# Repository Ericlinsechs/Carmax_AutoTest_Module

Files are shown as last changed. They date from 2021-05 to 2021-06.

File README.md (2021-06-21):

# 自動化治具盒 Carmax Auto-test Module

- Github URL : https://github.com/Ericlinsechs/Carmax_AutoTest_Module
- This module is featured by conbining several test functions into one single box, the functions of it contains :
1. 深度測試功能
2. 布條紋測試功能
3. AOA斷線測試功能
4. 電流檢測功能
5. 連續紀錄10秒電流值功能

# How to use it

If you want to carry out tests immediately instead of editing the code or change the hardware, this chapter is fitting on you.

## Prerequisites

Before start using it, there are some stuffs you need to prepare.

- The components of the module include :
1. Auto-test module
2. 12V power cable (alligator clip)
3. Current monitor adapter
<p align="left">
  hover text
</p>

- Some extra components are required :
1. USB outlet power adapter
2. USB to micro-USB cable
3. 12v power supplyer
<p align="left">
  hover text
</p>

## Usage

### Hardware Setting Up
1. Connecting 5v power cable to the module.
<p align="left">
  hover text
</p>

2. Connecting 12v power cable to power supplyer.
<p align="left">
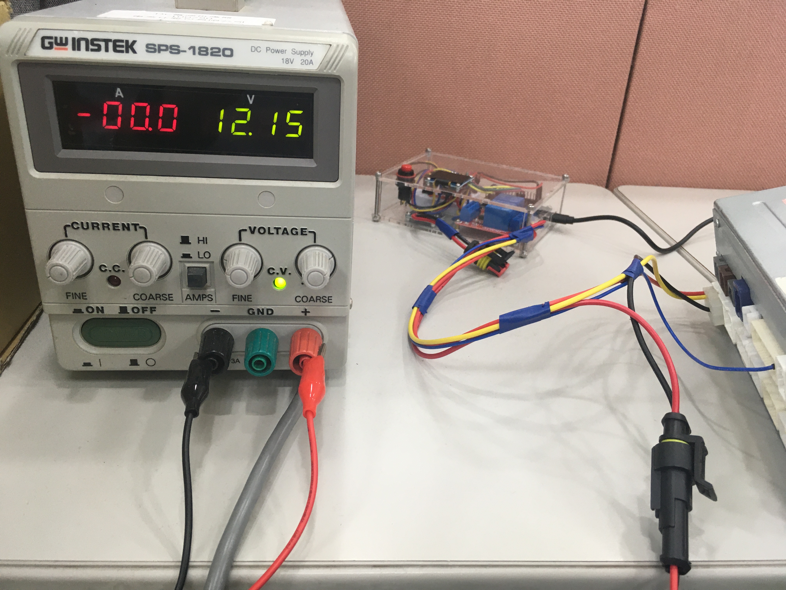
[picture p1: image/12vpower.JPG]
  
</p>

3. Connecting the connector below to DA machine.
<p align="left">
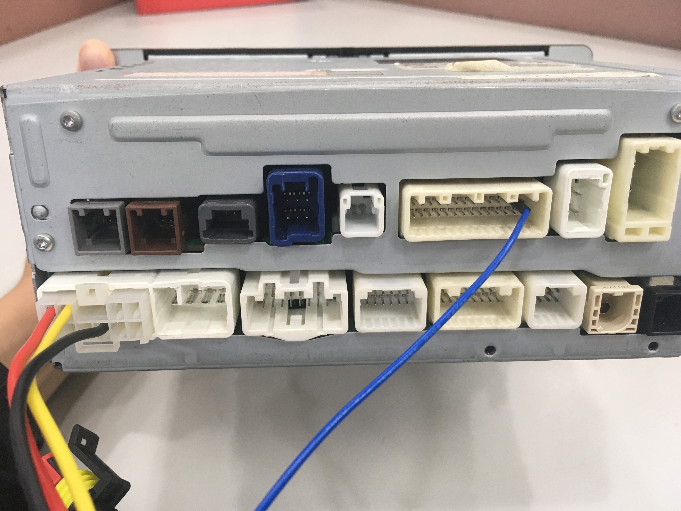
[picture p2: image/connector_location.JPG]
  
</p>

4. Connecting the Rev pin below to DA machine(connect to Pin No.2 from top right side of the connector).
<p align="left">
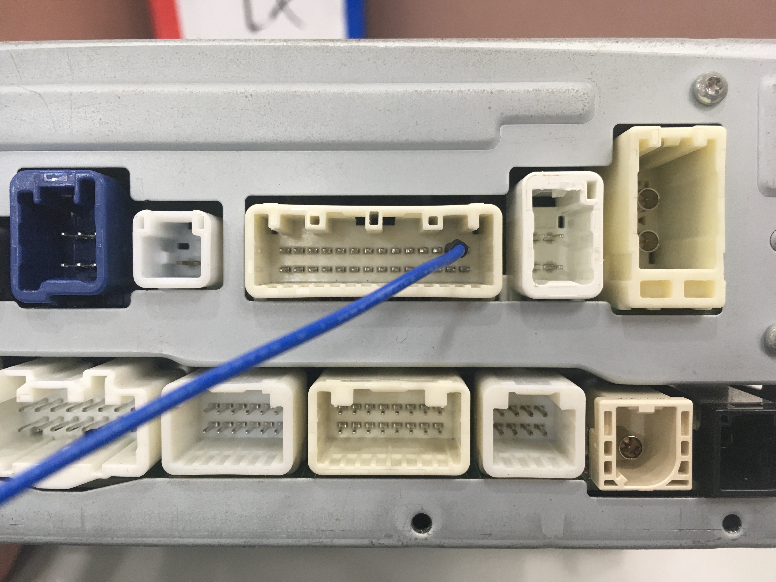
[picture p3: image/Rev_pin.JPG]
  
</p>

5. Connecting to electronic object(ex: E-mirror) serially(Only function No.4 and No.5 needed).

### Getting Started
1. Once 5v power cable is connected, you would see the **welcome message** on the displayer on the box.
<p align="left">
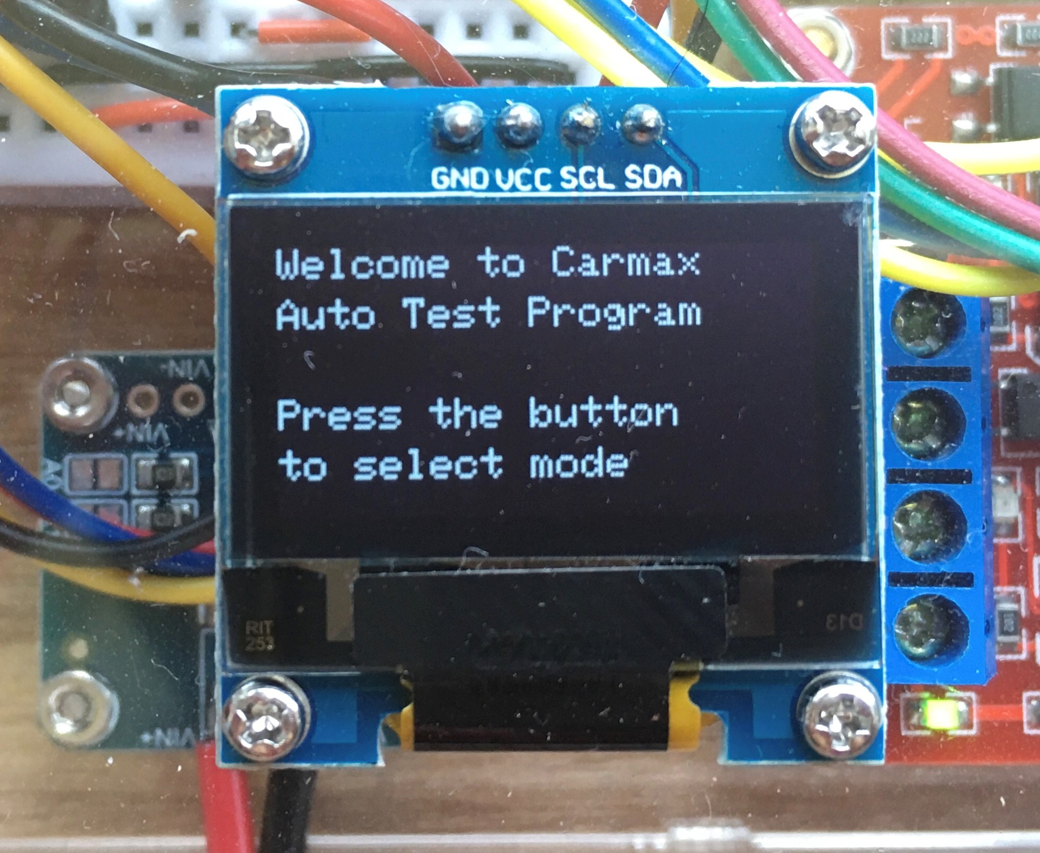
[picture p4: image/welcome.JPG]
  
</p>

2. After press the button on the left side of the displayer, it would enter mode selecting process, choose which test function you want to run it.
<p align="left">
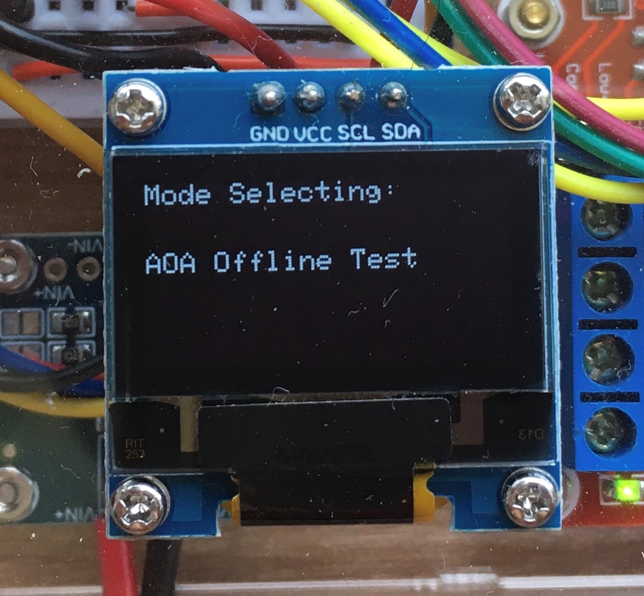
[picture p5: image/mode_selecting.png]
  
</p>

3. When you finish your selecting, mode selecting process will be ended after 5 seconds (the countdown is on the bottom right side of the displayer).
4. Before the test is running, you would see the **ready to test** message.
<p align="left">
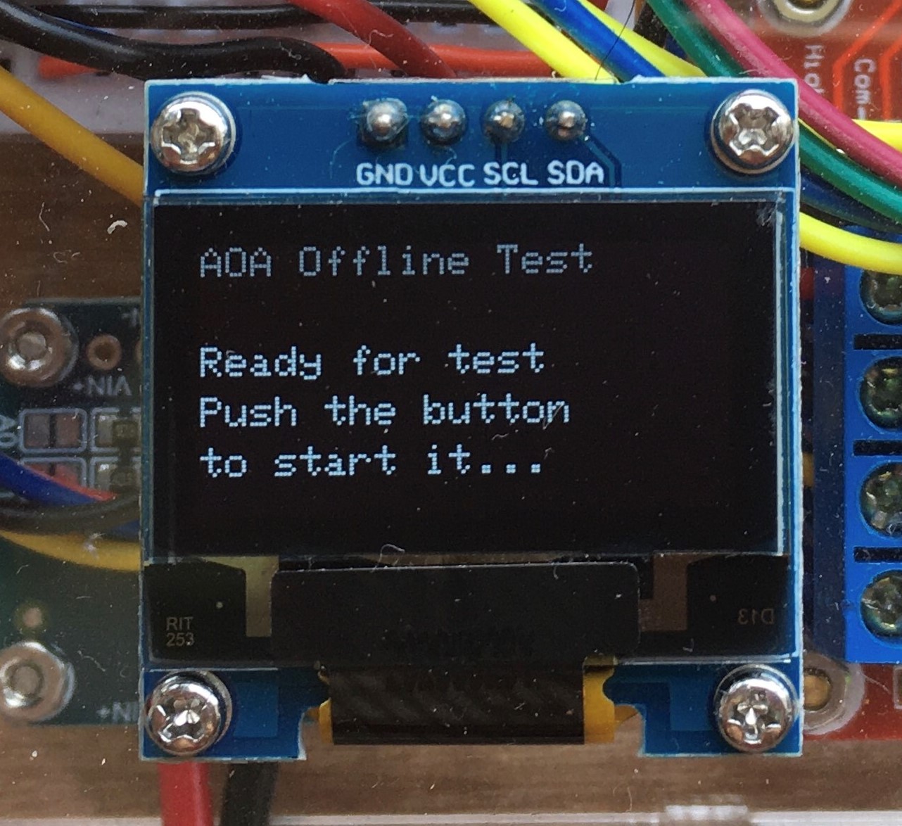
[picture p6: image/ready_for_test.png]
  
</p>

5. Press the button again to start the test.

### Function No.5 (連續紀錄10秒電流值功能)
#### Software
- [python 3.7.4](https://www.python.org/downloads/windows/) 
- [Atom python editor](https://atom.io/) (addition)
- [Anaconda3](https://www.anaconda.com/products/individual#Downloads)
- [pip](https://pip.pypa.io/en/stable/installing/)
- Python Pandas Package
  - `pip install pandas`
- Python Numpy Package
  - `pip install numpy`
- Python Requests Package 
  - `pip install requests`
- Python Beautifulsoup4 Package 
  - `pip install beautifulsoup4` 

#### Wifi Connection
- Due to upload current measurements onto website, wifi connecting is essential. 
1. Connecting Wifi is required when running the function No.5, default wifi setting is Samsung Galaxy Noto 20, if you want to change wifi, please check [current_monitor.h](https://github.com/Ericlinsechs/Carmax_AutoTest_Module/blob/main/code/Auto_Test_Box_code/libraries/Current_Monitor/Current_Monitor.h).
<p align="left">
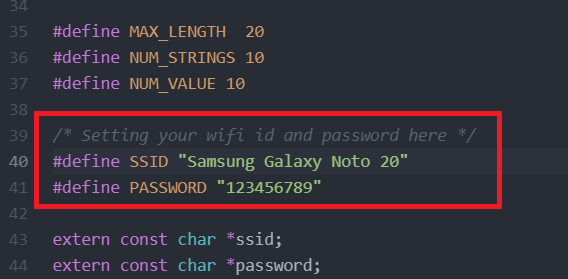
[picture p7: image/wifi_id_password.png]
  
</p>

2. Connect the same Wifi as the auto-test box did on your computer, then search the IP on the website.
<p align="left">
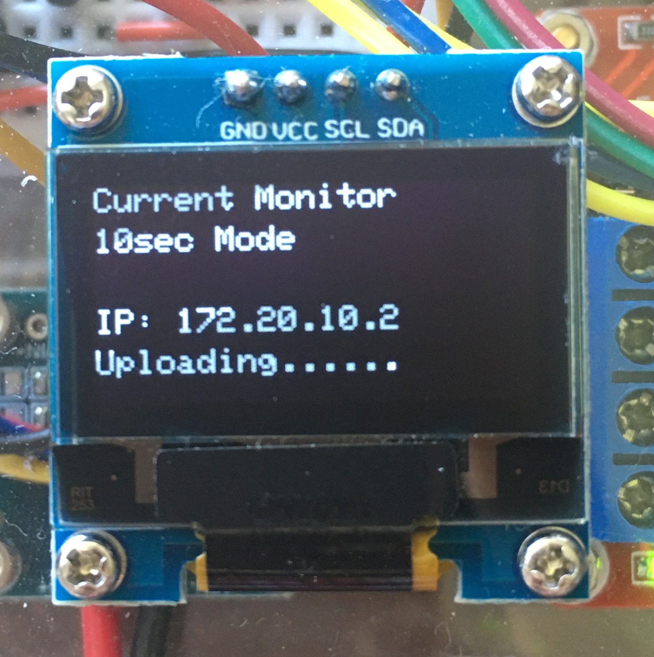
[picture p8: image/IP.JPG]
  
</p>

3. You should see the current measurement on the webpage.
<p align="left">
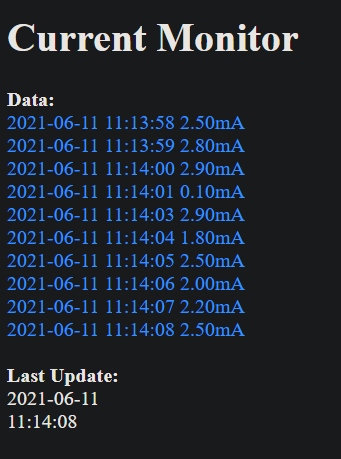
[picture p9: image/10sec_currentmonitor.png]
  
</p>

#### Webcrawler
- This part describes how we crawl the data from website and then save as a .csv file.
1. After installed Anaconda3, add these route to [PATH](https://helpdeskgeek.com/windows-10/add-windows-path-environment-variable/) :
  - `C:\Users\username\Anaconda3`
  - `C:\Users\username\Anaconda3\Scripts`
  - `C:\Users\username\Anaconda3\Library\bin`
2. Find [webcrawler_code.py](https://github.com/Ericlinsechs/Carmax_AutoTest_Module/blob/main/code/webcrawler_code/webcrawler_code.py) on your computer and open it.
3. Create a CSV file on your computer.
<p align="left">
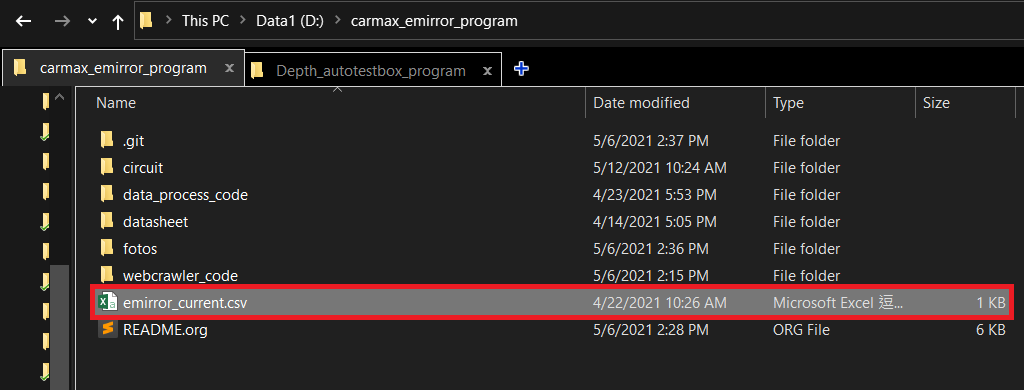
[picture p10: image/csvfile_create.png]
  
</p>

4. Change IP and route of the CSV file you just created.
<p align="left">
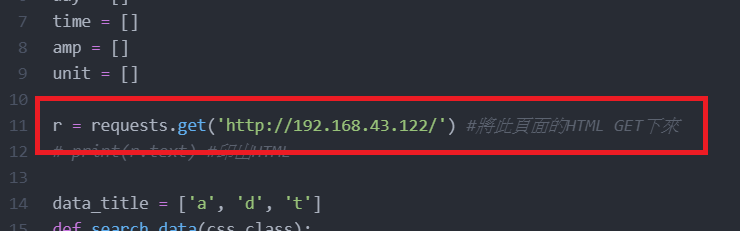
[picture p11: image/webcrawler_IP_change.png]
  
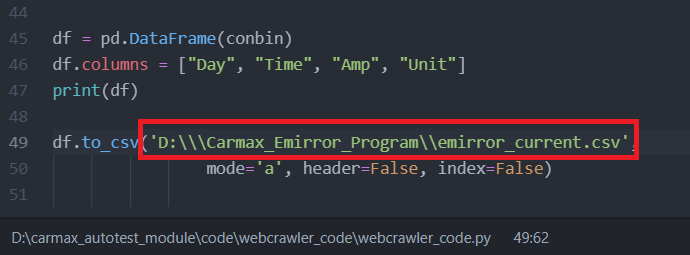
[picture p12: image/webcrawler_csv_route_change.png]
  
</p>

5. Run `pyhton [route]/webcrawler_code.py` on cmd and check the data in CSV file.

- [Tutorial Reference](https://ithelp.ithome.com.tw/articles/10202121)

#### Windows Task Manager
- Using Windows task manager to run webcrawler code automatically.
- [Batch file](https://github.com/Ericlinsechs/Carmax_AutoTest_Module/blob/main/code/webcrawler_code/emirror_crawler.bat)
- [Tutorial Reference](https://titangene.github.io/article/set-up-windows-task-scheduler-to-periodically-execute-python-crawler.html)
#### Conda environment (if needed)
- [Tutorial Reference](https://titangene.github.io/article/create-a-virtual-environment-and-manage-dependencies-with-conda.html)
### **CAUTION**
- It's designed to be **non-stop** on each test function.
- If you desire a halt during the test, press the button between the time a test round is done and next one haven't start yet.
- Before function No.4 or No.5 is running, please make sure the voltage and current won't over the spec bellow :
  - **MAX voltage: 32v current: 1A (default)**
# Pin Definition
<p align="left">
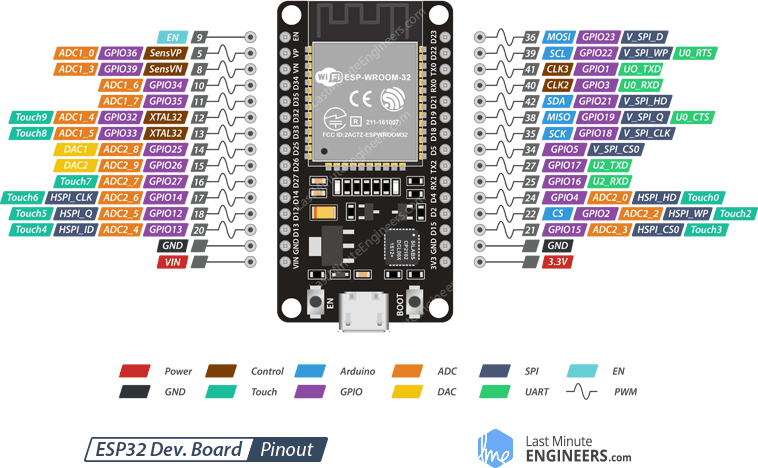
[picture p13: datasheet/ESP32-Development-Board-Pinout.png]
  
</p>

<p align="left">
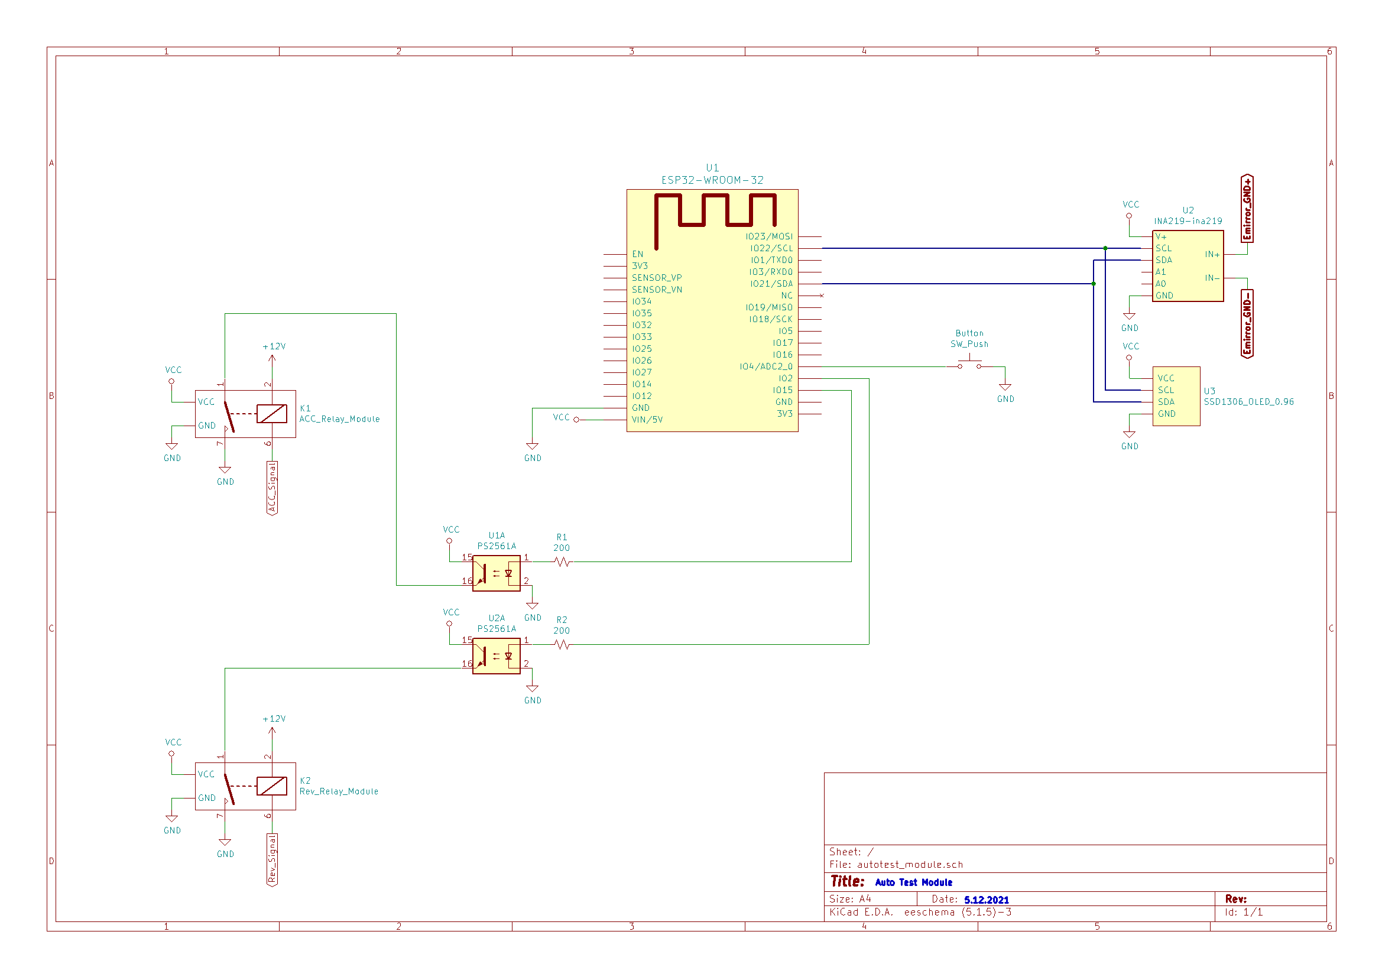
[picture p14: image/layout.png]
  
</p>

# Code Uploading Set Up (addition)
Only for code uploaded requirement would need to check this chapter.

## Prerequisites
### Software
- [ArduinoIDE](https://www.arduino.cc/en/software)
- [Atom python editor](https://atom.io/)
- [python 3.7.4](https://www.python.org/downloads/windows/) 

## Getting Started
### Installation
- Copy this `git clone https://github.com/Ericlinsechs/Carmax_AutoTest_Module.git /.` to your terminal(cmd or so on) and exeuted.
- Copy these [libraries](https://github.com/Ericlinsechs/Carmax_AutoTest_Module/tree/main/code/Auto_Test_Box_code/libraries) into this path(default)`C:\Users\[Username]\Documents\Arduino\libraries`
- Copy [auto_Test_Box_Program](https://github.com/Ericlinsechs/Carmax_AutoTest_Module/tree/main/code/Auto_Test_Box_code/Auto_Test_Box_Program) dir into this path(default)`C:\Users\[Username]\Documents\Arduino`
##### ESP32 Setting
- Stable release link: `https://raw.githubusercontent.com/espressif/arduino-esp32/gh-pages/package_esp32_index.json`
- Enter the release links above into Additional Board Manager URLs field.
- Run the command below to install esp32 package :
  - `git clone "https://github.com/espressif/arduino-esp32.git" C:/Users/[YOUR_USER_NAME]/Documents/Arduino/hardware/espressif/esp32`
  - `git submodule update --init --recursive`
- Open `[ARDUINO_SKETCHBOOK_DIR]/hardware/espressif/esp32/tools and double-click get.exe`
- Now you should upload the code without error.
- [Tutorial Reference](https://github.com/espressif/arduino-esp32)
#### Arduino library
- Install Adafruit Library
  - `Adafruit ina219 library`
  - `Adafruit GFX library` 
  - `Adafruit ssd1306 library`
- Install The Network Time Protocol (NTP) Library
  - [NTP library link](https://github.com/taranais/NTPClient)
 ### Code uploading
 - [Tutorial Reference](https://www.arduino.cc/en/Tutorial/getting-started-with-ide-v2/ide-v2-uploading-a-sketch)
 - Press BOOT button everytime when you upload code, then press RESET to exeucte it.
 - It may cause a bit time to upload, please be patient.
 # Additional Reference
 - [ESP32 Arduino: Getting started with WiFi](https://techtutorialsx.com/2017/06/29/esp32-arduino-getting-started-with-wifi/)
 - [I2C Scanner](https://create.arduino.cc/projecthub/abdularbi17/how-to-scan-i2c-address-in-arduino-eaadda)
 - [Adafruit_INA219](https://learn.adafruit.com/adafruit-ina219-current-sensor-breakout)
 - [Adafruit_SSD1306](https://github.com/adafruit/Adafruit_SSD1306)

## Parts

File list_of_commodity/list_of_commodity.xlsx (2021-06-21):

Cost summary |  | 統編: 22660624 抬頭:車美仕股份有限公司
Line Num. | Order Status | Name of commodity | Desription | Each One Needed | Total Needed | Unit Cost | Quantity | Deliver Cost | Total Cost | Tax | URL
1 | V | 壓克力板加工 |  | 1 | 3 | $945.00 | 1 |  | $945.00 | V | 阿宏 (https://shopee.tw/product/9171064/2037578994)
2 | V | M2*4+3 六角銅柱 | M2 六角長度: 4 牙長: 5 牙距: 0.4 | 12 | 36 | $2.00 | 44 | $50.00 | $138.00 | V | (M2)(M3)(M4)單通六角銅柱 (https://shopee.tw/(M2)(M3)(M4)%E5%96%AE%E9%80%9A%E5%85%AD%E8%A7%92%E9%8A%85%E6%9F%B1-%E5%A4%9A%E7%A8%AE%E5%85%AD%E8%A7%92%E6%9F%B1%E9%95%B7%E5%BA%A6%E5%8F%AF%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)
3 | V | M2 螺絲 | M2*6 頭d : 3.2 thick : 1.6 | 16 | 48 | $2.00 | 60 | $50.00 | $170.00 | V | 樂泰膠水 磁鐵 螺絲 螺帽 木工 塑膠螺絲(全館含稅附發票) (https://shopee.tw/%E3%80%90%E8%AB%8B%E8%A9%A2%E5%83%B9%E5%BE%8C%E8%B3%BC%E8%B2%B7%E3%80%91%E4%B8%8D%E9%8F%BD%E9%8B%BC%E7%99%BD%E9%90%B5-m1-m1.2-m1.4-m1.6-m2-%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)
3 | V | M2 螺帽 | 六角對邊: 4 厚度: 1.6 unit : 10 | 32 | 96 | $10.00 | 6 |  | $60.00 | V | 樂泰膠水 磁鐵 螺絲 螺帽 木工 塑膠螺絲(全館含稅附發票) (https://shopee.tw/%E3%80%90%E8%AB%8B%E8%A9%A2%E5%83%B9%E5%BE%8C%E8%B3%BC%E8%B2%B7%E3%80%91%E4%B8%8D%E9%8F%BD%E9%8B%BC%E7%99%BD%E9%90%B5-m1-m1.2-m1.4-m1.6-m2-%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)
4 | V | M3 螺帽 | 六角對邊: 5.5 厚度: 2.4 unit : 10 | 4 | 12 | $10.00 | 2 |  | $20.00 | V | m3不鏽鋼螺帽 (https://shopee.tw/m2m2.-5-m2.6-m3-m3.5-m4-m5-m6-m8m10-m12%E4%B8%8D%E9%8F%BD%E9%8B%BC%E8%9E%BA%E5%B8%BD-%E7%99%BD%E9%90%B5%E5%85%AD%E8%A7%92%E8%9E%BA%E5%B8%BD-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)
5 | V | M3 螺絲 | M3*35 白鐵有頭內六角 unit : 10支 | 4 | 12 | $25.00 | 2 |  | $50.00 | V | 白鐵螺絲 M3 (https://shopee.tw/%E7%89%99%E5%BE%91m3*%E9%95%B74~60mm%E5%90%84%E5%B0%BA%E5%AF%B8%E4%B8%8D%E9%8F%BD%E9%8B%BC%E6%9D%AF%E9%A0%AD%E5%85%A7%E5%85%AD%E8%A7%92-%E7%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)
6 | V | AMP型 HID 接頭 | 1.5mm 端子 3P | 1 | 3 | $25.00 | 5 | $50.00 | $175.00 | V | louishoma (https://shopee.tw/product/3001351/7240589310)
6 | V | AMP型 HID 接頭 | 1.5mm 端子 2P | 1 | 3 | $20.00 | 5 |  | $100.00 | V | louishoma (https://shopee.tw/product/3001351/7240589310)
7 | V | AMP型 1.5mm端子 | 公 | 5 | 15 | $3.00 | 10 |  | $30.00 | V | louishoma (https://shopee.tw/AMP-%E5%BF%AB%E9%80%9F%E6%8E%A5%E9%A0%AD-%E5%85%AC%E7%AB%AF%E5%AD%90(%E5%90%AB%E9%BB%83%E8%89%B2%E6%A9%A1%E8%86%A0%E5%A1%9E%E5%AD%90)-3%E5%8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)
8 | V | AMP型 1.5mm端子 | 母 | 5 | 15 | $3.00 | 20 |  | $60.00 | V | louishoma (https://shopee.tw/AMP-%E5%BF%AB%E9%80%9F%E6%8E%A5%E9%A0%AD-%E5%85%AC%E7%AB%AF%E5%AD%90(%E5%90%AB%E9%BB%83%E8%89%B2%E6%A9%A1%E8%86%A0%E5%A1%9E%E5%AD%90)-3%E5%8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)
9 | V | 圓型開關 | 10mm 小開關 圓型開關 | 1 | 3 | $15.00 | 4 | $50.00 | $110.00 | V | 祥昌電子 (https://shopee.tw/%E3%80%90%E7%A5%A5%E6%98%8C%E9%9B%BB%E5%AD%90%E3%80%9110mm-%E5%B0%8F%E9%96%8B%E9%97%9C-%E5%9C%93%E5%9E%8B%E9%96%8B%E9%97%9C-%E5%9C%93%E5%BD%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)
10 | V | 20 AWG線材 | 紅 unit : 1M | 1 | 3 | $6.00 | 5 |  | $30.00 | V | 祥昌電子 (https://shopee.tw/%E3%80%90%E7%A5%A5%E6%98%8C%E9%9B%BB%E5%AD%90%E3%80%91UL1007%E5%A4%9A%E8%8A%AF%E7%B7%9A-16AWG-18AWG-20AWG-24AWG-28AWG-%E6%B1%BD%E6%A9%9F%E8%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)
11 | V | 20 AWG線材 | 黑 unit : 1M | 1 | 3 | $7.00 | 5 |  | $35.00 | V | 祥昌電子 (https://shopee.tw/%E3%80%90%E7%A5%A5%E6%98%8C%E9%9B%BB%E5%AD%90%E3%80%91UL1007%E5%A4%9A%E8%8A%AF%E7%B7%9A-16AWG-18AWG-20AWG-24AWG-28AWG-%E6%B1%BD%E6%A9%9F%E8%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)
12 | V | 熱縮套管 | 4mm(黑) unit : 1m | 1 | 3 | $12.00 | 5 |  | $60.00 | V | 祥昌電子 (https://shopee.tw/%E3%80%90%E7%A5%A5%E6%98%8C%E9%9B%BB%E5%AD%90%E3%80%91UL1007%E5%A4%9A%E8%8A%AF%E7%B7%9A-16AWG-18AWG-20AWG-24AWG-28AWG-%E6%B1%BD%E6%A9%9F%E8%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)
13 | V | ESP-WROOM-32 | ESP32 開發板 WIFI+藍牙 | 1 | 3 | $195.00 | 3 | $50.00 | $635.00 | V | 樂意創客 (https://shopee.tw/%E3%80%90%E6%A8%82%E6%84%8F%E5%89%B5%E5%AE%A2%E5%AE%98%E6%96%B9%E5%BA%97%E3%80%91%E3%80%8A%E9%99%84%E7%99%BC%E7%A5%A8%E3%80%8BESP32-%E9%96%8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)
14 | V | SSD1306 oled 0.96吋 | OLED顯示器 | 1 | 3 | $120.00 | 3 |  | $360.00 | V
15 | V | INA219 | 電源監控感測器模組感測器 | 1 | 3 | $58.00 | 3 | $50.00 | $224.00 | V | allen (https://shopee.tw/%E2%96%BA938%E2%97%84INA219-I2C-%E4%BB%8B%E9%9D%A2%E9%9B%B6%E6%BC%82%E7%A7%BB-%E9%9B%99%E5%90%91%E9%9B%BB%E6%B5%81-%E9%9B%BB%E6%BA%90%E7%9B%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)
16 | V | 迷你麵包板 | 迷你麵包板 | 1 | 3 | $10.00 | 3 |  | $30.00 | V | allen (https://shopee.tw/%E2%96%BA938%E2%97%84INA219-I2C-%E4%BB%8B%E9%9D%A2%E9%9B%B6%E6%BC%82%E7%A7%BB-%E9%9B%99%E5%90%91%E9%9B%BB%E6%B5%81-%E9%9B%BB%E6%BA%90%E7%9B%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)
17 | V | 2路relay模組 |  | 1 | 2 | $110.00 | 2 |  | $220.00 | V
18 | V | ps2561光耦合元件 | 3.3V訊號控制5V訊號給Relay module | 1 | 3 |  | 5 |  | $0.00
19 | V | 杜邦端子 | 自行壓接用 | 10 | 30 |  | 30 |  | $0.00
20 | V | 主機電源接頭 |  | 1 | 3 | $0.00 | 3 | $0.00 | $0.00
21 | V | 主機電源接頭端子 |  | 3 | 9 | $0.00 | 9 | $0.00 | $0.00
22 |  | M2 螺帽 | 六角對邊: 4 厚度: 1.6 unit : 10 |  | 50 | $10.00 | 5 | $50.00 | $100.00
23 |  | micro usb to usb |  |  | 2 | $35.00 | 2 | $50.00 | $120.00
22 |  | 28p接頭 | Rev訊號 | 1 | 3 | $0.00 | 3 | $0.00 | $0.00
23 |  | 28p接頭端子 |  | 1 | 3 | $0.00 | 3 | $0.00 | $0.00
 |  |  |  |  |  |  |  | Total : | $3672.00

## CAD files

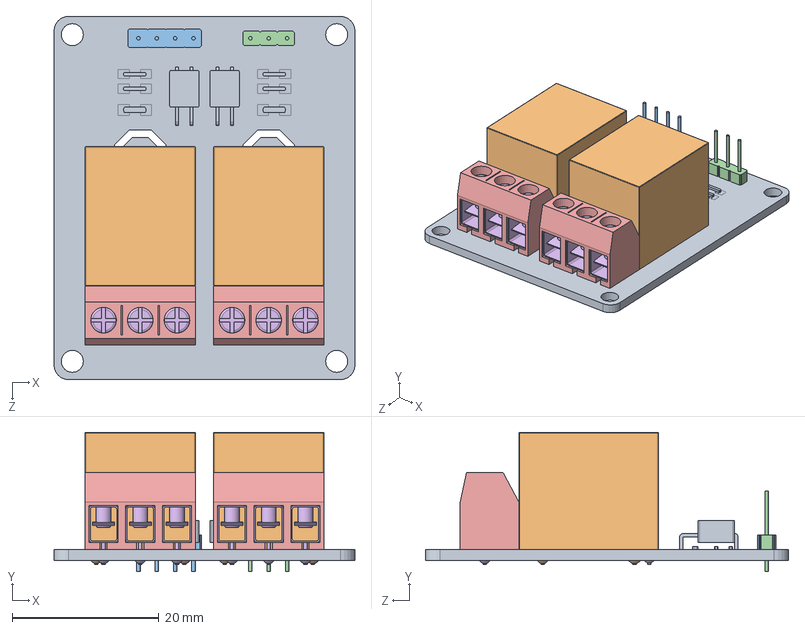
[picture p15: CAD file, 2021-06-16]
CAD/2-channel-5v-relay-module-1.snapshot.2/2PH63091A Parts/Relay - 2 Channel - 2PH63091A - Montaj.SLDASM
41.0 x 19.0 x 49.5 mm
2PH63091A Board
Relay Body x 2
4 Headers
Headers
Clamp Body x 2
Metal Clamp Part x 6

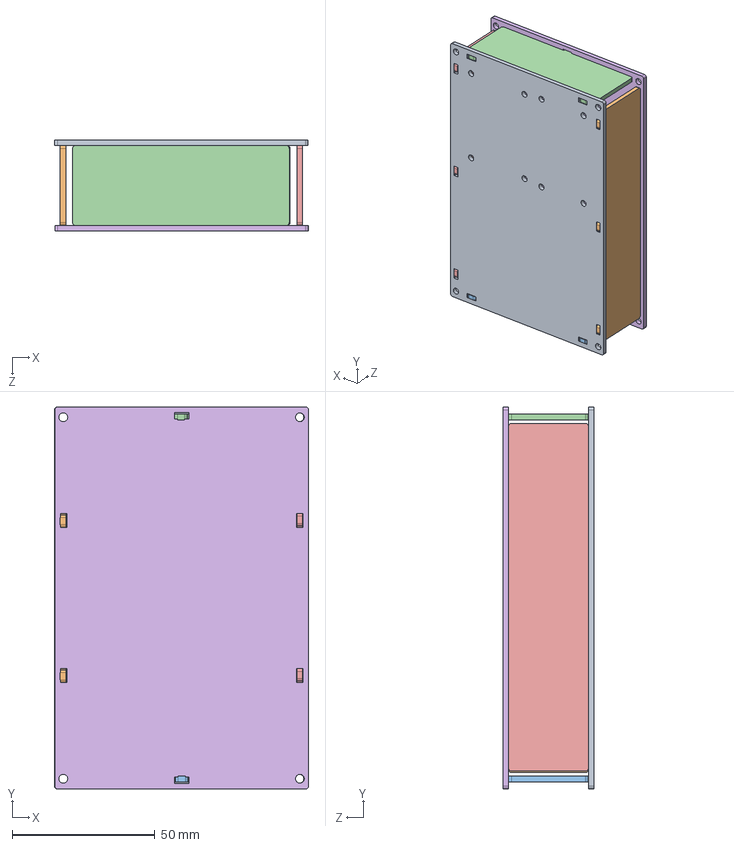
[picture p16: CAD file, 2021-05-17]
CAD/acrylic/acrylicbox_assem.SLDASM
89.1 x 134.0 x 32.0 mm
bottom
Leftside_wall
backside_wall
frontside_wall
rightside_wall
lid

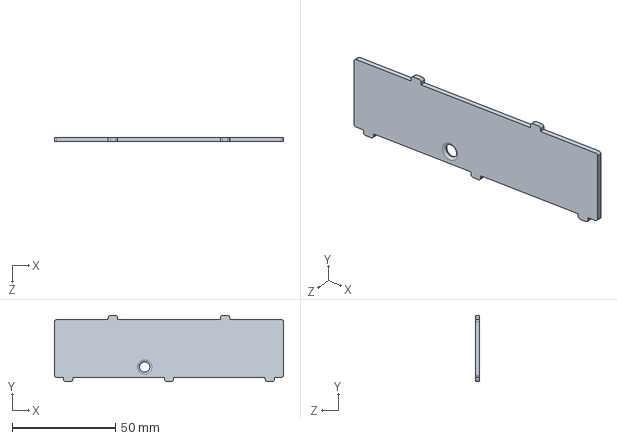
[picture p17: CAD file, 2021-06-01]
CAD/acrylic/rightside_wall.SLDPRT
111.0 x 32.0 x 2.00 mm

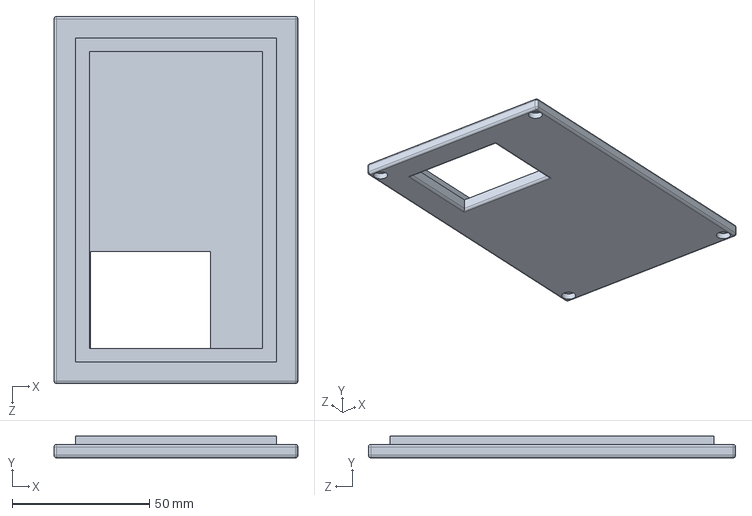
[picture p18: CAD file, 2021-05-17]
CAD/autotest_boxcover.SLDPRT
89.0 x 8.00 x 134.0 mm

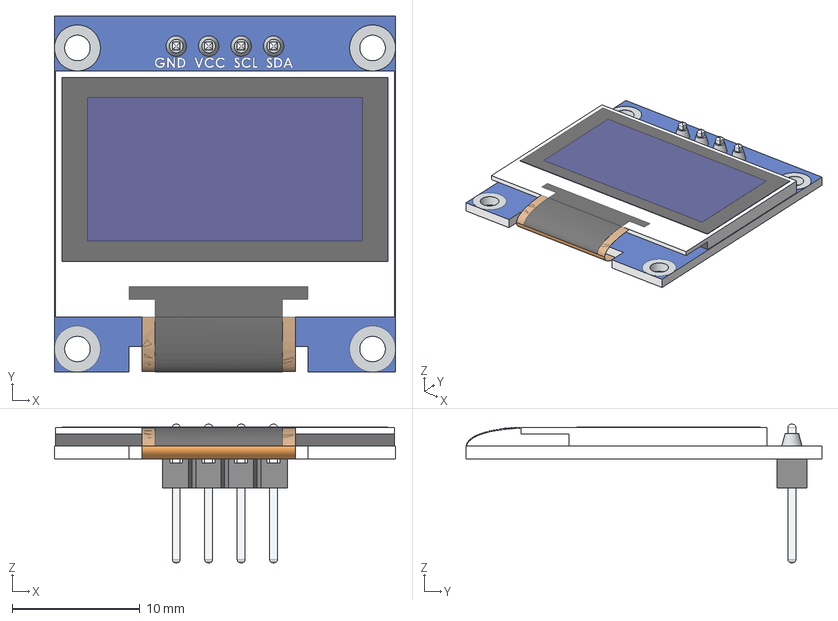
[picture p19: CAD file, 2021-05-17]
CAD/display-oled-ssd1306-CAD/OLED-128x64-0.96.step
26.7 x 27.9 x 10.8 mm

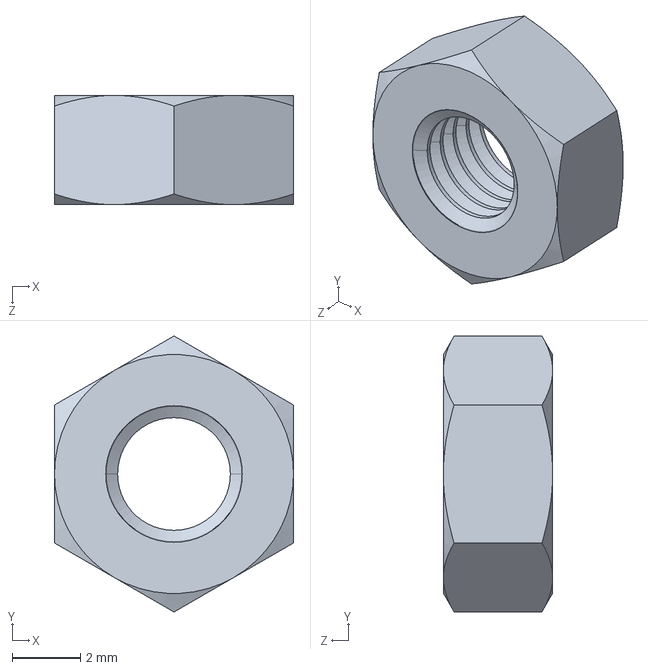
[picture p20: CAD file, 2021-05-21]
CAD/Hex Nut/M4.STEP
7.00 x 8.08 x 3.20 mm

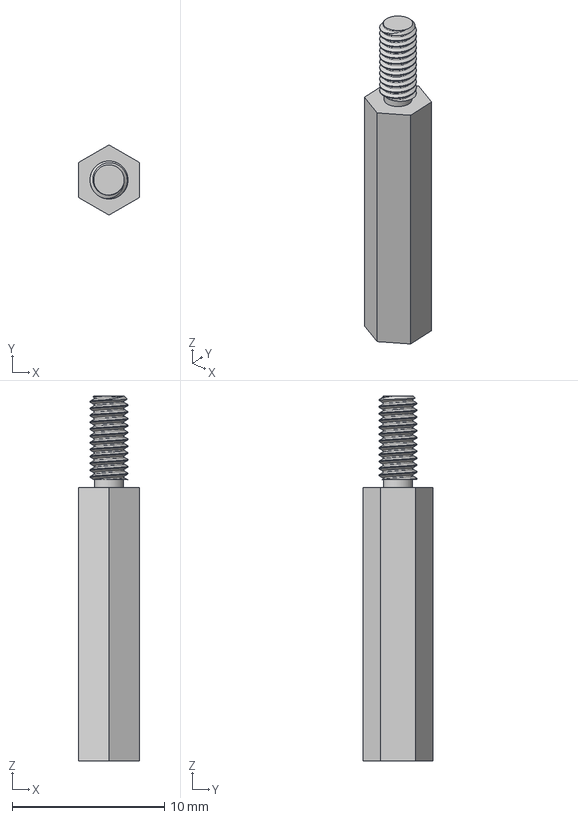
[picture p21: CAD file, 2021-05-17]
CAD/hex-spacer-standoff_m2-5_CAD/hex spacer standoff_M2_5 SW4 L18.stp
4.00 x 4.62 x 24.0 mm

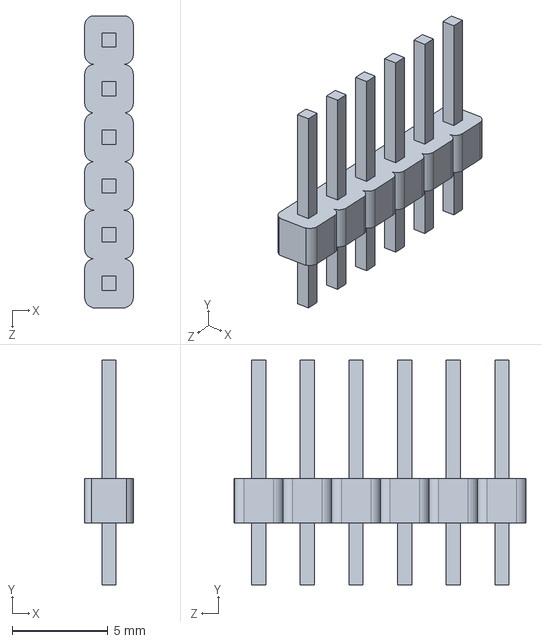
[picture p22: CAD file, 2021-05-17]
CAD/ina219_CAD/6 Header-Pin.SLDPRT
2.54 x 11.8 x 15.2 mm

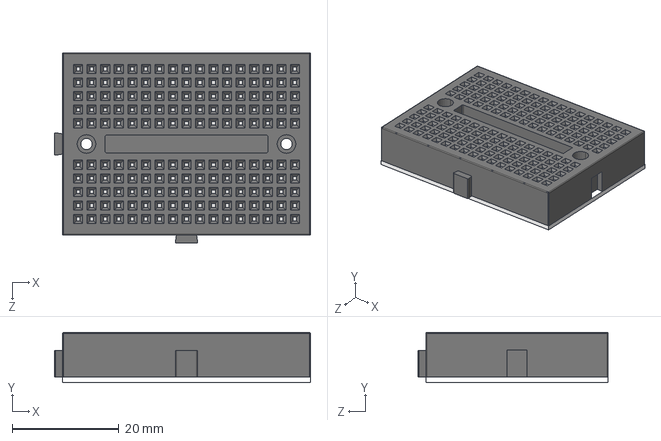
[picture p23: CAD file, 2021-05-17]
CAD/mini _breadboard_CAD/Mini-Black.STEP
48.0 x 9.40 x 35.7 mm

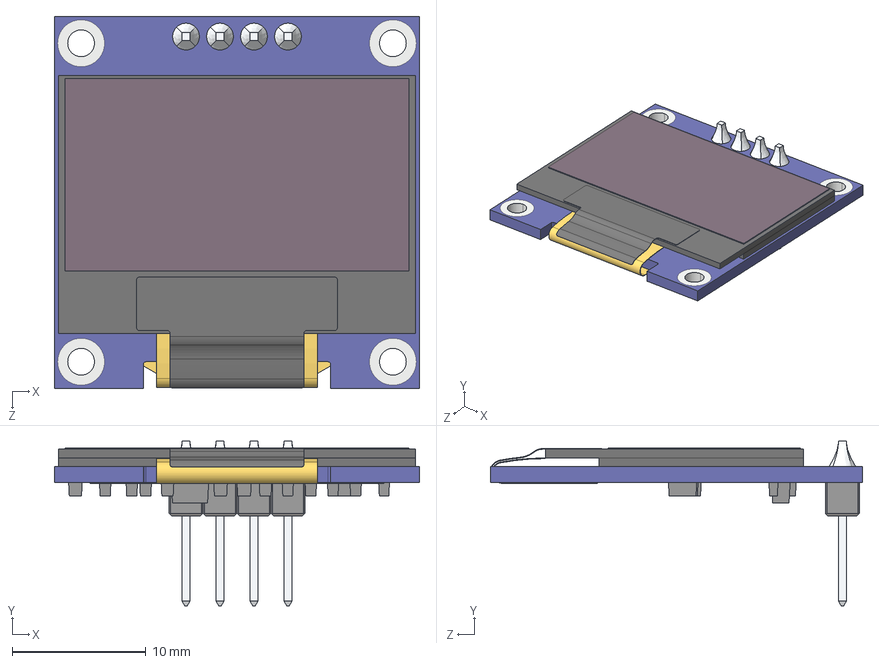
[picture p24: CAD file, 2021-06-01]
CAD/oled-tft-0-96-inch-64x128-monochrome-i2c-1.snapshot.2/OLED TFT 0.96 inch 64x128 monochrome.STEP
27.3 x 12.3 x 27.8 mm

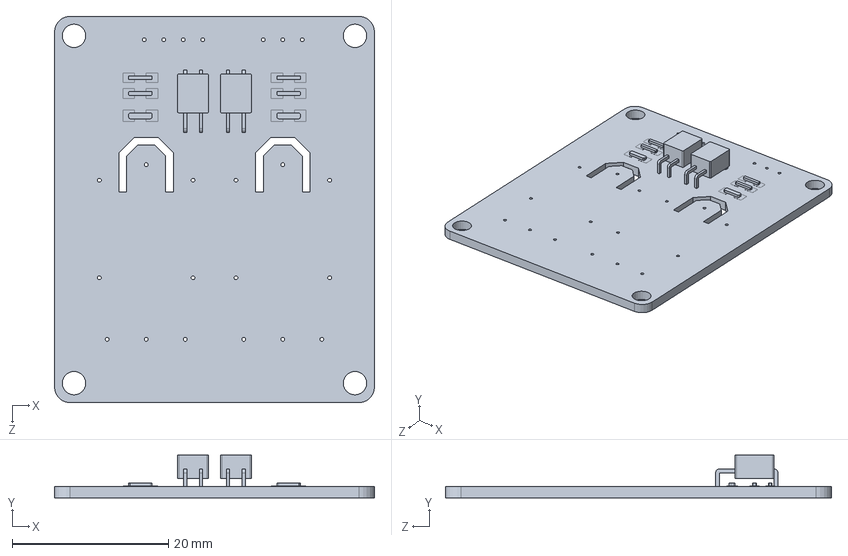
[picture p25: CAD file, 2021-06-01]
CAD/2-channel-5v-relay-module-1.snapshot.2/2PH63091A Parts/2PH63091A Board.SLDPRT
41.0 x 5.50 x 49.5 mm

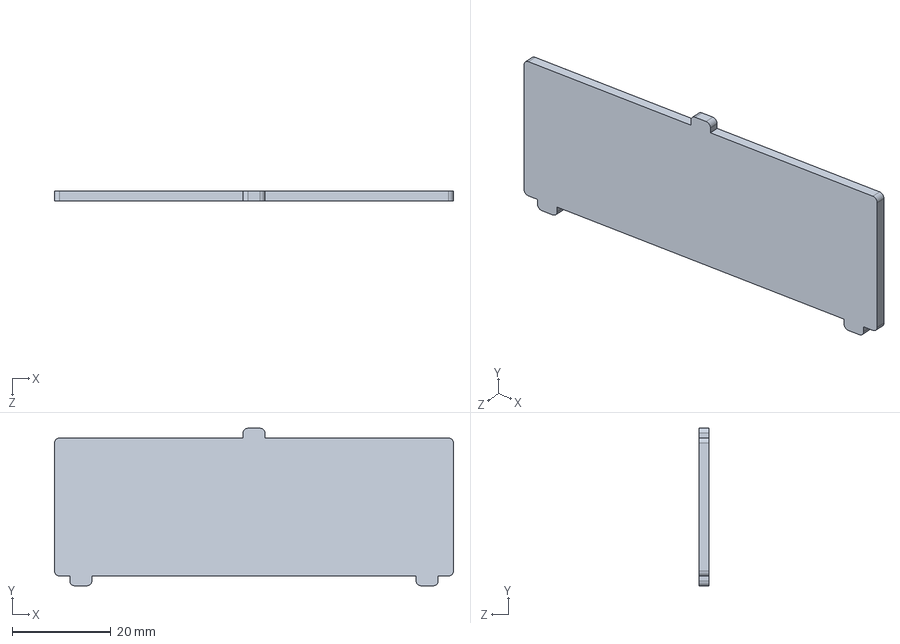
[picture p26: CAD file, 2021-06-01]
CAD/acrylic/backside_wall.SLDPRT
81.0 x 32.0 x 2.00 mm

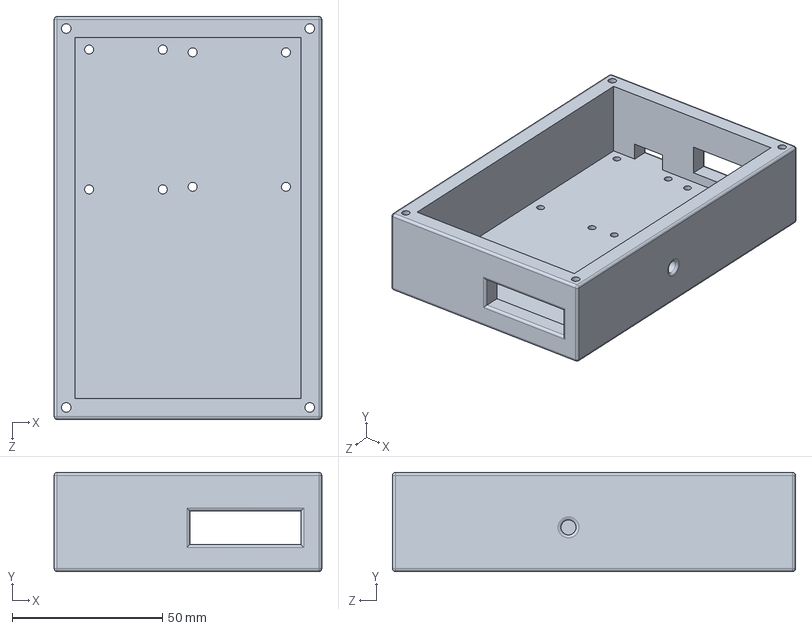
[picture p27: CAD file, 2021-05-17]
CAD/autotest_box.SLDPRT
89.0 x 33.0 x 134.0 mm

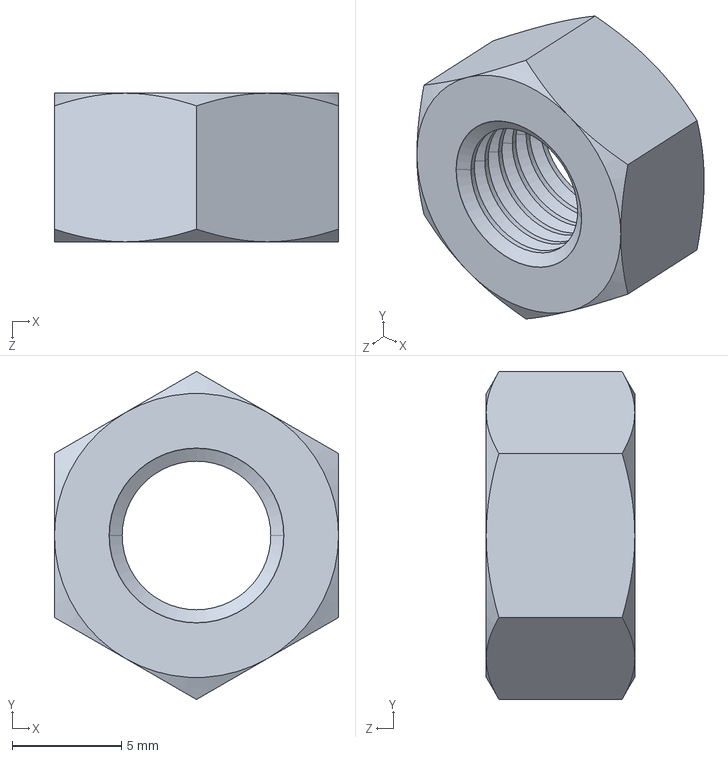
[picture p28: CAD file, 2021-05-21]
CAD/Hex Nut/M8.STEP
13.0 x 15.0 x 6.80 mm

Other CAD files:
CAD/hex-spacer-standoff_m2-5_CAD/hex spacer standoff_M2_5 SW4 L20.stp
CAD/ina219_CAD/Placa.SLDPRT
CAD/mini _breadboard_CAD/Mini-Blue.STEP
CAD/2-channel-5v-relay-module-1.snapshot.2/2PH63091A Parts/4 Headers.SLDPRT
CAD/2-channel-5v-relay-module-1.snapshot.2/2PH63091A Parts/Clamp Body.SLDPRT
CAD/2-channel-5v-relay-module-1.snapshot.2/2PH63091A Parts/Headers.SLDPRT
CAD/2-channel-5v-relay-module-1.snapshot.2/2PH63091A Parts/Metal Clamp Part.SLDPRT
CAD/2-channel-5v-relay-module-1.snapshot.2/2PH63091A Parts/Relay Body.SLDPRT
CAD/4-digit 7-segment-display module for Arduino v1.step
CAD/Hex Nut/M10.STEP
CAD/Hex Nut/M2.STEP
CAD/Hex Nut/M3.STEP
CAD/Hex Nut/M5.STEP
CAD/Hex Nut/M6.STEP
CAD/RelayBoard.STEP
CAD/acrylic/Leftside_wall.SLDPRT
CAD/acrylic/bottom.SLDPRT
CAD/acrylic/dwg/Leftside_wall.DWG
CAD/acrylic/dwg/Leftside_wall.SLDDRW
CAD/acrylic/dwg/backside_wall.DWG
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

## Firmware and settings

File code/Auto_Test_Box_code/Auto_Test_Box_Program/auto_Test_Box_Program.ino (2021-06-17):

/*
 * Auto Test Box Program
 * Editor: Eric Lin
 * Date: 2021/06/16
 *
 * The auto-test box is a multi-function test tool,
 * The multi-function including:
 * 1. 深度測試
 * 2. 布條紋測試
 * 3. AOA斷線測試
 * 4. 電流值檢測功能
 * 5. 連續紀錄10秒電流值功能
 * Through press the button to decide which test would you like to execute.
 * Also, it's really flexible to combine other new test function if needed.
 *
 */

#include <Arduino.h>
#include "Depth_Autotest.h"
#include "Displayer_SSD1306.h"
#include "Current_Monitor.h"
#include "Shift_Mode.h"
#include "soc/soc.h"
#include "soc/rtc_cntl_reg.h"

#define ACCPIN 15
#define REVPIN 2
#define BUTTONPIN 4
#define DEBOUNCE_TIME 250
volatile uint32_t DebounceTimer = 0;

/* Pin to which the button, PIR motion detector or radar is connected */
uint8_t button_count = 1;

bool flag;
byte _mode;

DepthAutoTest depthautotest(ACCPIN, REVPIN);  // DepthAutoTest initialize
CurrentMonitor currentmonitor;
Displayer_SSD1306 ssd1306;
WebPage webpage;
ShiftMode shiftmode;

/* Interrupt function, if interrupt is trigger, this func would be executed*/
void IRAM_ATTR buttonpressed() {
  if ( millis() - DEBOUNCE_TIME  >= DebounceTimer ) {          // Preventing debounce of button
    DebounceTimer = millis();
    shiftmode.button_function(button_count);
  }
}

void setup() {
    WRITE_PERI_REG(RTC_CNTL_BROWN_OUT_REG, 0);                 // Disable brownout detector
    Serial.begin(115200);
    currentmonitor.CurrentMonitor_initialize(ACCPIN, REVPIN);  // CurrentMonitor initialize
    Displayer_SSD1306();                                       // Oled Displayer SSD1306 initialize
    pinMode(BUTTONPIN, INPUT_PULLUP);
    attachInterrupt(BUTTONPIN, buttonpressed, FALLING);        // Setting button as a interrupt trigger
    shiftmode.welcome_message();
    _mode = shiftmode._ShiftMode(ACCPIN, REVPIN);              // Entering mode selecting
}

void loop() {
  /* Depend on the value of _mode, different test function would be selected */
  /* 深度測試 */
  if (_mode == 0) {
    while(1)
      depthautotest._DepthAutoTest();
  }
  /* 布條紋測試 */
  if (_mode == 1) {
    while(1)
      depthautotest.RippleAutoTest();
  }
  /* AOA斷線測試 */
  if (_mode == 2) {
    while(1)
      depthautotest.AOAOffline();
  }
  /* 電流值檢測功能 */
  if (_mode == 3) {
    while(1)
      currentmonitor.CurrentMonitor_INA219();
  }
  /* 連續紀錄10秒電流值功能 */
  if (_mode == 4) {
    while(1) {
      currentmonitor.CurrentMonitor_INA219_10sec();
      webpage.ServerClient();
    }
  }
}

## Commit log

2021-05-12 added CAD
    [4-digit 7-segment-display module for Arduino v1.step, RelayBoard.STEP, terminal_block_6.stp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]
2021-05-17 added cad file
    [6 Header-Pin.SLDPRT, INA219.SLDASM, INA219.STEP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]
2021-05-21 Update cad and list
    [Leftside_wall.DWG, Leftside_wall.SLDPRT, M10.STEP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]
2021-06-01 code added
    [2PH63091A Board.SLDPRT, 4 Headers.SLDPRT, Clamp Body.SLDPRT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]
2021-06-16 code added comment
    [INA219.SLDASM, Relay - 2 Channel - 2PH63091A - Montaj.SLDASM, autotest_module.sch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]
2021-06-18 update layout
    [autotest_module.sch]
2021-06-21 added purchase list
    [list_of_commodity.xlsx]
